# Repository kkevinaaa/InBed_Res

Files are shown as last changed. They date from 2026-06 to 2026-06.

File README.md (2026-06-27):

## 设备设计

### 1.1 目标

本项目制作一个小型立方体番茄钟。设备顶面放置小尺寸单色 OLED 屏幕，用于显示当前时间、倒计时、电量和状态。与顶面相邻的四个侧面均可作为接触桌面的“底面”，用户通过翻滚立方体 90° 启动或切换计时状态。

设备不设置实体按钮，主要依赖姿态变化和摇晃动作交互。外壳面向 3D 打印设计，预留 Type-C 充电口，内部结构便于拆卸、调试和后续缩小体积。

### 1.2 交互与功能

设备默认处于时钟状态，屏幕显示当前时间和电量。长时间无操作后，OLED 熄灭，设备进入低功耗状态。轻微晃动或姿态变化会重新点亮屏幕。

立方体翻滚到指定侧面并稳定放置后，开始一次番茄钟计时，默认 25 分钟。计时过程中，屏幕显示剩余时间。计时结束后，蜂鸣器提醒，并显示结束状态，随后返回时钟状态。

计时过程中检测到暂停姿态，即屏幕面朝上时，设备暂停当前计时，屏幕面重新转向侧面时恢复计时。

计时过程中检测到取消姿态时，设备停止当前计时，短暂显示暂停提示后回到时钟状态。

快速摇晃用于进入 BLE 设置模式。一般情况下 BLE 关闭，只有快速摇晃触发后短时间开启。手机连接后设置当前时间、默认番茄钟时长、蜂鸣提醒方式、屏幕熄灭时间等参数。设置完成或连接超时后关闭 BLE。

```mermaid
stateDiagram-v2
    [*] --> IdleClock

    IdleClock: 时钟显示
    ScreenOff: 熄屏低功耗
    PomodoroRunning: 番茄钟计时
    PomodoroPaused: 暂停提示
    Alarm: 结束提醒
    BLESetting: BLE 设置模式

    IdleClock --> ScreenOff: 无操作超时
    ScreenOff --> IdleClock: 轻微晃动 / 姿态变化

    IdleClock --> PomodoroRunning: 翻滚到计时面并稳定放置
    PomodoroRunning --> Alarm: 倒计时结束
    Alarm --> IdleClock: 蜂鸣提醒结束

    PomodoroRunning --> PomodoroPaused: 翻滚到暂停/取消姿态
    PomodoroPaused --> IdleClock: 暂停提示结束

    IdleClock --> BLESetting: 快速摇晃
    ScreenOff --> BLESetting: 快速摇晃
    BLESetting --> IdleClock: 设置完成 / 连接超时
```

### 1.3 硬件方案

主控使用 ESP32-C3，开发环境为 PlatformIO + Arduino framework。ESP32-C3 负责读取传感器、驱动屏幕、控制蜂鸣器，并通过 BLE 与手机通信。

屏幕使用 SSD1327 单色 OLED。OLED 采用黑底白字显示，没有 TFT 背光常亮问题，适合电池供电设备。第一版只要求清晰显示时间、电量、倒计时和状态提示。

姿态检测使用 SC7A20H 三轴加速度传感器，通过 I2C 与 ESP32-C3 通信。第一阶段使用轮询读取三轴数据，调试六面识别、稳定放置判断、轻微晃动唤醒和快速摇晃检测。后续使用 INT 引脚做低功耗运动中断唤醒。

提醒部分使用 12085 蜂鸣器，阻抗约 16Ω。蜂鸣器通过 MOSFET 或三极管由 GPIO 控制。若使用无源蜂鸣器，ESP32-C3 输出 PWM；若使用有源蜂鸣器，GPIO 只控制开关。

电池使用小型单节聚合物锂电池。充电接口为 Type-C，充电电路使用单节锂电充电保护方案。系统电源可先采用电池升压到 5V 后接 ESP32-C3 开发板，也可后续改为电池经 3.3V 稳压/升降压后直接供电。电量检测第一版使用电阻分压接 ADC，后续可改用 MAX17048 电量计。

### 1.4 低功耗策略

静息状态下关闭 OLED，ESP32-C3 进入低功耗模式，BLE 默认关闭，SC7A20H 保持低功耗运动检测。检测到运动后唤醒主控，再读取完整三轴数据并判断动作类型。

低功耗逻辑的核心是：屏幕不常亮，BLE 不常开，ESP32-C3 不长期高频轮询。第一版先验证功能，后续再优化中断唤醒和静态电流。

### 1.5 第一版范围

第一版验证核心功能，不追求极致小体积和最终外观。目标包括：OLED 显示时间、电量和倒计时；SC7A20H 识别六个方向；翻滚启动 25 分钟计时；翻滚暂停；计时结束蜂鸣提醒；快速摇晃进入 BLE 设置；BLE 设置基础参数；无操作熄屏；晃动唤醒。

第一版外壳先使用较大的 3D 打印结构，优先保证安装、拆卸、测量和调试方便。功能稳定后再优化内部布局、屏幕开窗、接口位置和整体尺寸。

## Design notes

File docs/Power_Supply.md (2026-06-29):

# 供电方案说明

## 1. 当前供电路线

当前供电部分分两条路线推进。第一条路线使用现成 TP4056 充电模块做整机功耗测试，重点测量模块原始静态电流，以及拆除指示灯和限流电阻后的空载、带载电流。该路线用于快速判断现成模块是否适合第一版原型。

第二条路线使用已经完成的 `Cube Power Manager` 电源管理板。该板使用 USB-C 作为 5V 输入，TP4054 负责单节锂电池充电，AP2112K-3.3 负责输出 3.3V，给 MCU、屏幕和传感器供电。相比“电池升压到 5V 再降压到 3.3V”的方案，这一路径更直接，损耗更低，也更接近最终整机结构。

## 2. 方案一：TP4056 模块测试

TP4056 模块作为快速验证方案，优点是便宜、易买、接线简单，适合先测整机平均电流、峰值电流和大致续航。缺点是模块通常带有充电/满电指示灯和额外电阻，会产生持续静态耗电，不一定适合低功耗设备长期使用。

模块到货后先测原始状态下的静态电流，再拆除 LED 和相关限流电阻后重新测量。若拆除指示灯后静态电流足够低，可以作为早期原型供电方案；若静态电流仍然偏大，则只作为测试工具，不进入最终设计。

## 3. 方案二：Cube Power Manager

`Cube Power Manager` 是当前自制供电板方案。它集成 USB-C 输入、单节锂电池充电、电池供电路径、3.3V 稳压输出、电池电压检测和测试点，目标是验证最终设备所需的基础电源链路。

USB-C 只用于取 5V 电源，不做数据通信。CC1 和 CC2 使用下拉电阻声明设备端，从而让普通 USB-C 电源正常输出 5V。USB 输入进入 VIN 后，一路供给充电芯片，另一路通过电源路径给系统供电。

TP4054 负责单节锂电池充电。PROG 电阻设定充电电流，CHRG 引脚可用于充电状态指示。电池端引出 VBAT，同时保留电池接口和测试点，方便测量充电状态、电池电压和充电电流。

系统电源路径使用 VIN、VBAT 和 VCC 三个核心节点。USB 插入时，系统优先由 VIN 供电；USB 拔出时，系统由电池供电。当前设计中使用肖特基二极管和 PMOS 构成基础电源切换路径，并预留通过二极管方式验证电源 OR 的可能性。

AP2112K-3.3 将系统电源稳压为 3.3V。3.3V 输出用于 MCU、OLED 和 SC7A20H 等低压器件。该方案避免先升压再降压，结构简单，但需要注意单节锂电电压接近 3.3V 时，LDO 会逐渐失去稳压余量。

BAT_ADC 用于检测电池电压。电池电压经过电阻分压后送入 MCU ADC，避免超过 MCU 引脚耐压。采样点并联小电容用于降低噪声和稳定 ADC 读数。

## 4. 测试点与后续验证

电源板应重点测试 VIN、VBAT、VCC、3V3、GND、BAT_ADC 和充电状态信号。测试顺序从 USB 输入开始，再检查充电芯片、电池端、电源路径、LDO 输出和 ADC 检测。

第一次上电时先不接 MCU 负载，单独确认 3.3V 输出正常。随后接入 MCU 和屏幕，观察启动瞬间是否掉压、LDO 是否发热、电池供电是否稳定、USB 插拔时系统是否异常复位。

后续若要优化低功耗，优先检查三处：充电模块或指示灯带来的静态耗电，LDO 自身静态电流，以及电池电压检测分压电阻的持续耗电。

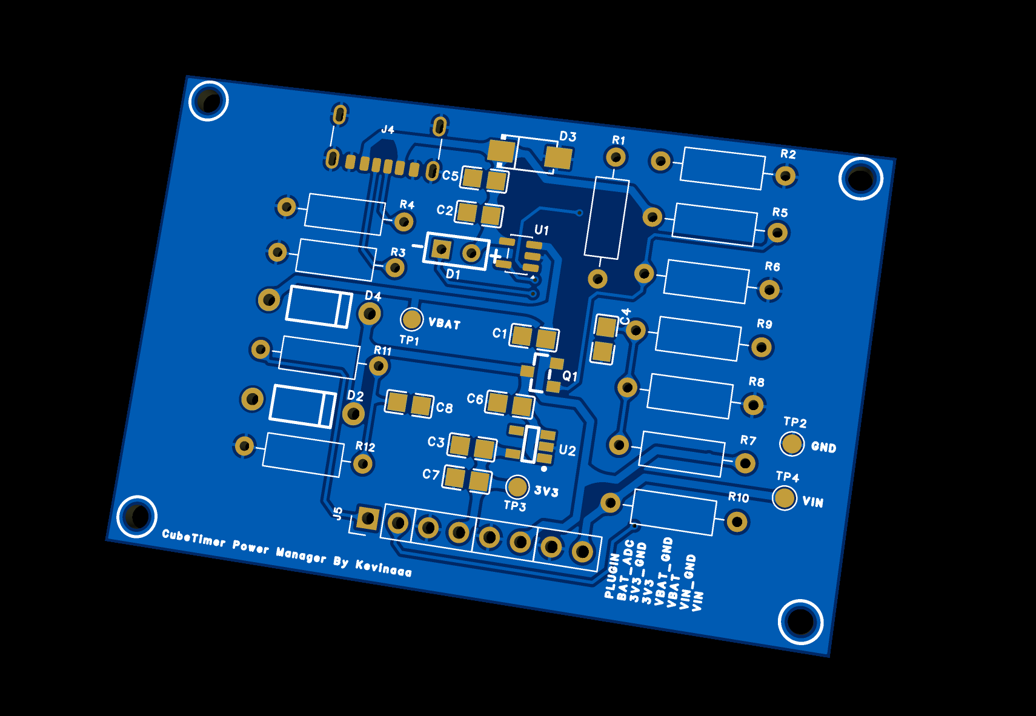
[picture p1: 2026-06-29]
hardware/power_manager/Pics/d412c011-9bdf-4567-bb50-f9bbbd0711b7.png

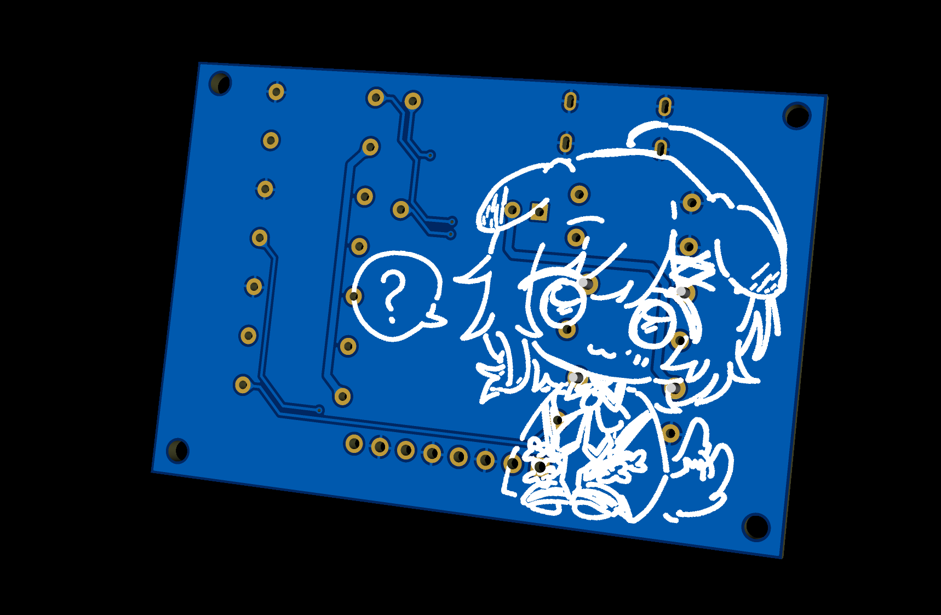
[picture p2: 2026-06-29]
hardware/power_manager/Pics/3ba6615dcab4c9ef26ad207464008806.png

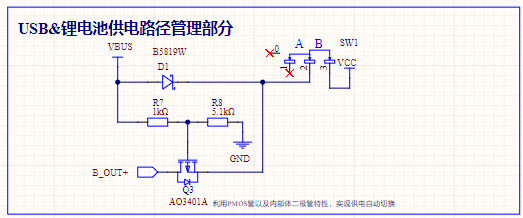
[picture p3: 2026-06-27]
docs/reference/旁路供电.png

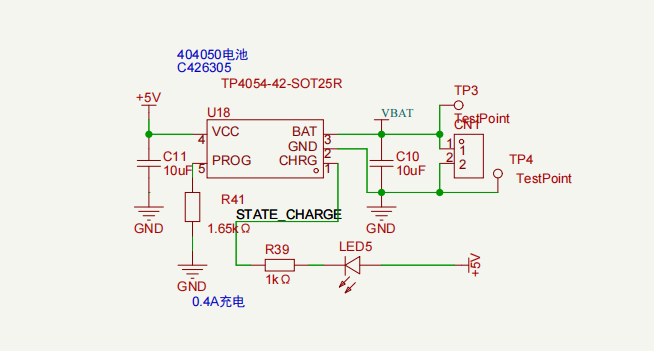
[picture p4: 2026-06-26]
docs/reference/TP4054.png

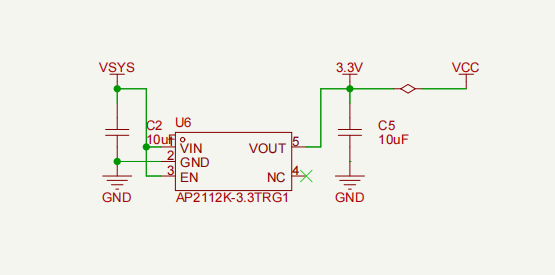
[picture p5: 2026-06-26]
docs/reference/AP2112K.png

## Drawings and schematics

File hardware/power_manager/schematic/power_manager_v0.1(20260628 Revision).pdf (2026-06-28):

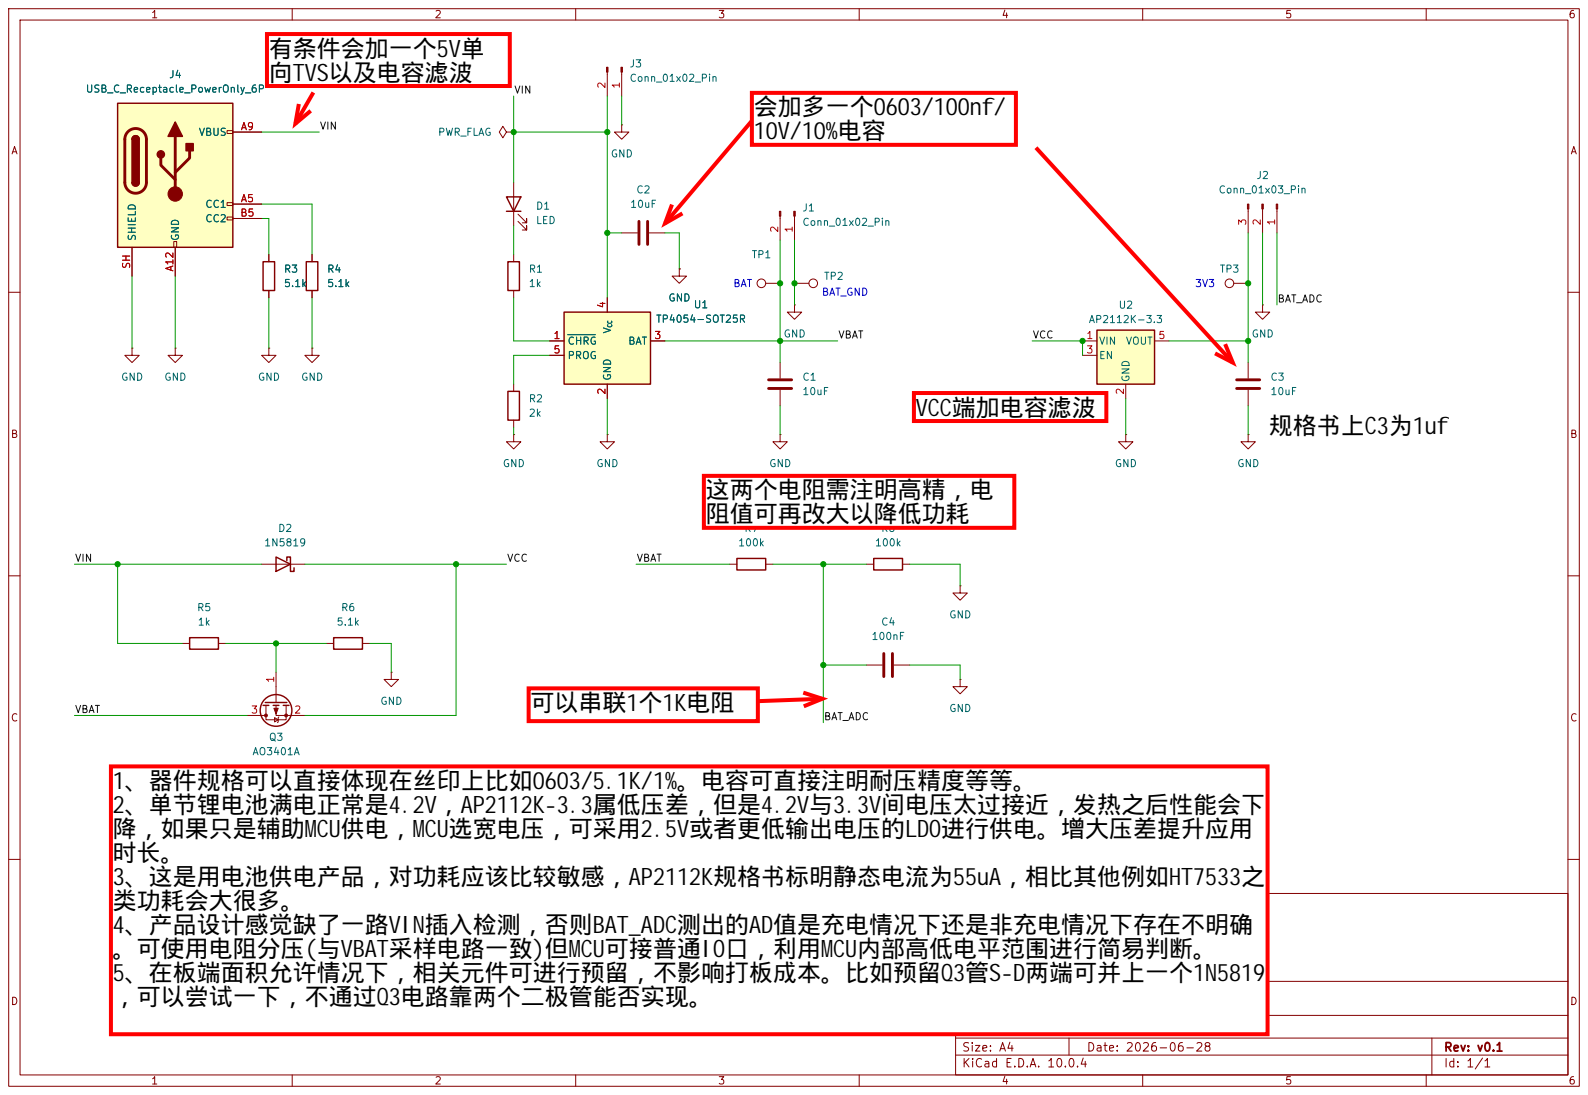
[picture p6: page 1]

Sheet: /
File: power_manager.kicad_sch
Title: Cube Power Manager

Size: A4 | Rev: v0.1
KiCad E.D.A. 10.0.4 | Id: 1/1

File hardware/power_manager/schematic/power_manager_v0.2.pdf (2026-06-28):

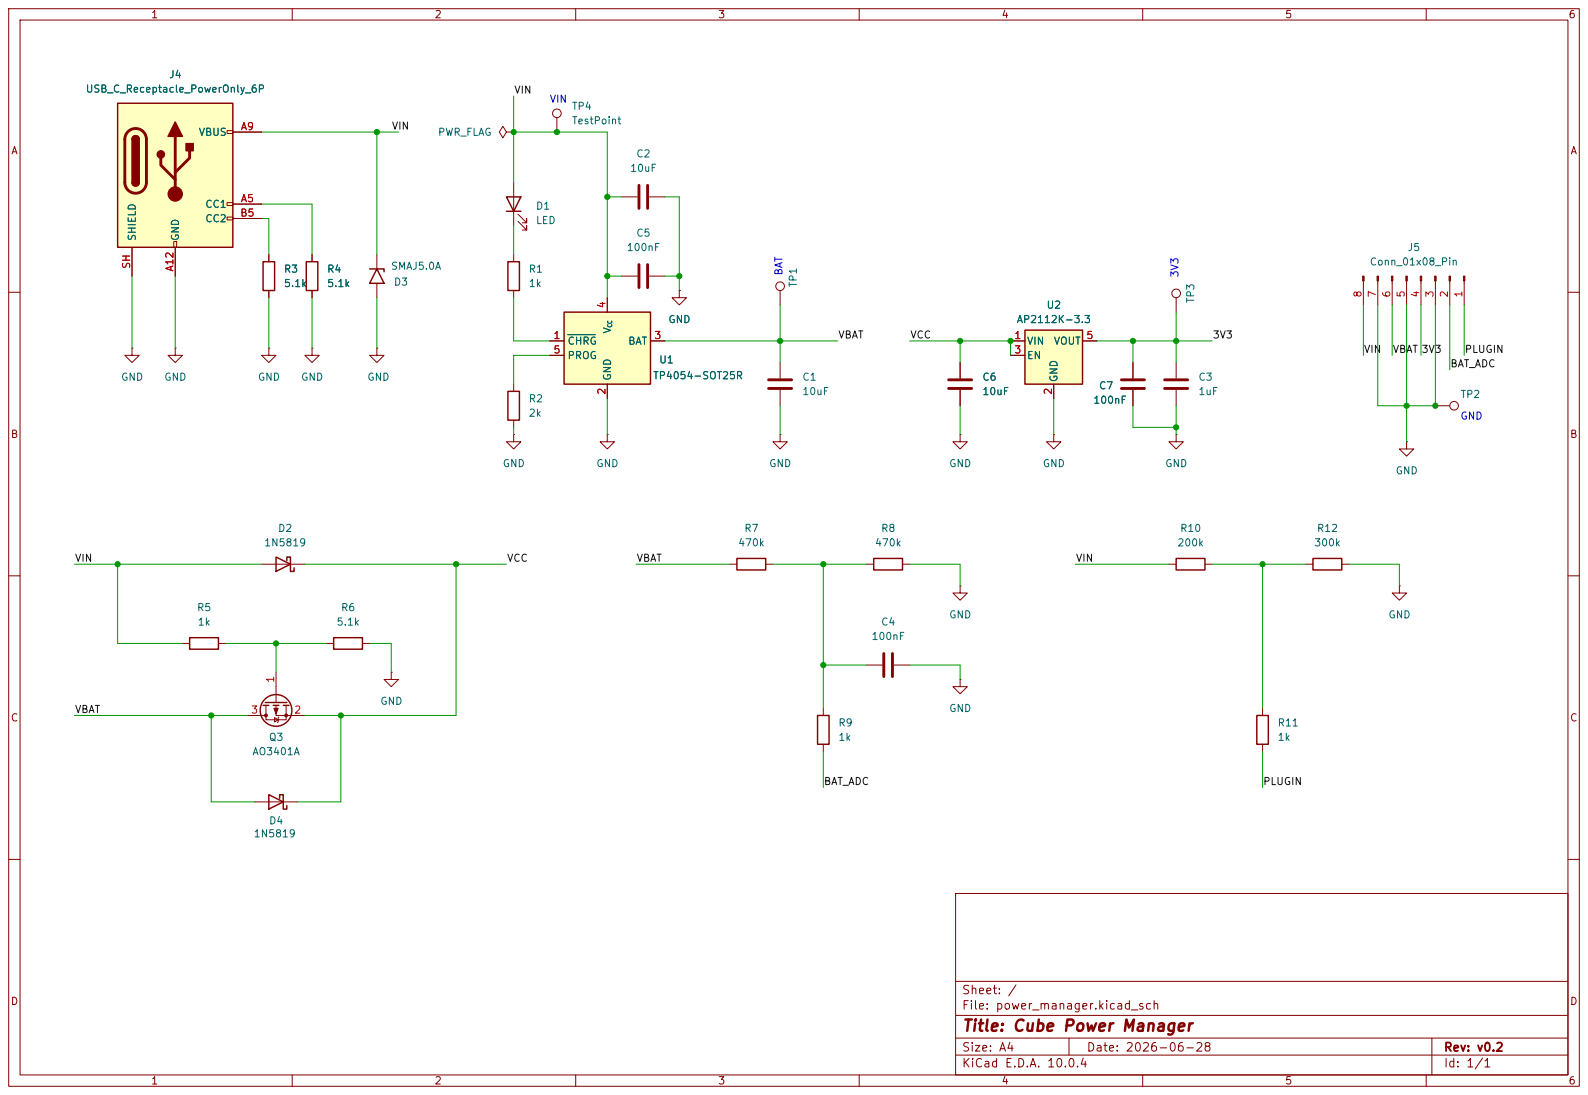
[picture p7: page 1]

Sheet: /
File: power_manager.kicad_sch
Title: Cube Power Manager

Size: A4 | Rev: v0.2
KiCad E.D.A. 10.0.4 | Id: 1/1

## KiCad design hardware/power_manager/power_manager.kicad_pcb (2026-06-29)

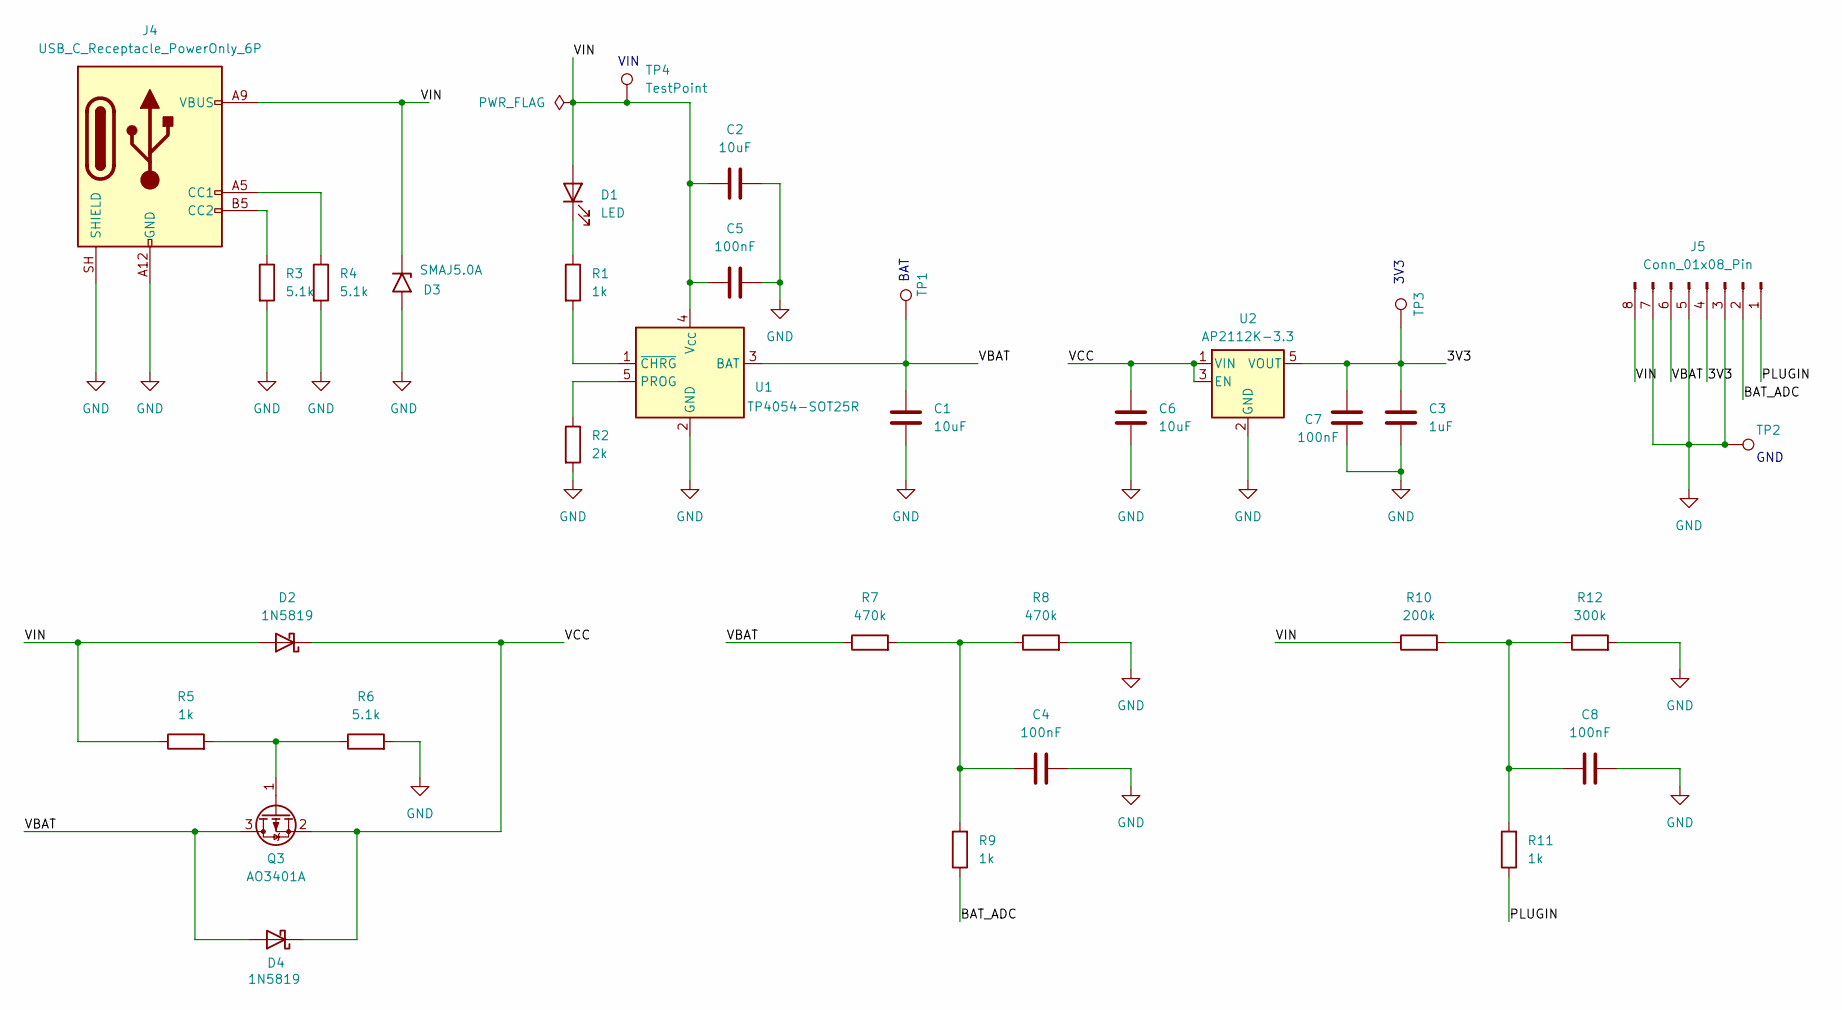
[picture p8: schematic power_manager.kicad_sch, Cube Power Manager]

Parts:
C1, C2, C6: 10uF; C_0805_2012Metric
C3: 1uF; C_0805_2012Metric
C4, C5, C7, C8: 100nF; C_0805_2012Metric
D1: LED; LED_D3.0mm
D2, D4: 1N5819; D_DO-41_SOD81_P10.16mm_Horizontal
D3: SMAJ5.0A; D_SMA
J4: USB_C_Receptacle_PowerOnly_6P; USB_C_Receptacle_GCT_USB4125-xx-x_6P_TopMnt_Horizontal
J5: Conn_01x08_Pin; PinHeader_1x08_P2.54mm_Vertical
Q3: AO3401A; SOT-23
R1, R5, R9, R11: 1k; R_Axial_DIN0207_L6.3mm_D2.5mm_P10.16mm_Horizontal
R2: 2k; R_Axial_DIN0207_L6.3mm_D2.5mm_P10.16mm_Horizontal
R3, R4, R6: 5.1k; R_Axial_DIN0207_L6.3mm_D2.5mm_P10.16mm_Horizontal
R7, R8: 470k; R_Axial_DIN0207_L6.3mm_D2.5mm_P10.16mm_Horizontal
R10: 200k; R_Axial_DIN0207_L6.3mm_D2.5mm_P10.16mm_Horizontal
R12: 300k; R_Axial_DIN0207_L6.3mm_D2.5mm_P10.16mm_Horizontal
TP1, TP2, TP3: TestPoint_Pad_D1.5mm
TP4: TestPoint; TestPoint_Pad_D1.5mm
U1: TP4054-SOT25R; TSOT-23-5
U2: AP2112K-3.3; SOT-23-5

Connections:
/3V3: C3.1, C7.2, J5.4, TP3.1 (1_1), U2.5 (VOUT)
/BAT_ADC: J5.2, R9.1
/PLUGIN: J5.1, R11.1
/VBAT: C1.1, D4.2 (A), J5.6, Q3.3 (D), R7.1, TP1.1 (1_1), U1.3 (BAT)
/VCC: C6.1, D2.1 (K), D4.1 (K), Q3.2 (S), U2.1 (VIN), U2.3 (EN)
/VIN: C2.1, C5.1, D1.2 (A), D2.2 (A), D3.1 (A1), J4.A9 (VBUS), J4.B9 (VBUS), J5.8, R5.1, R10.1, TP4.1 (1_1), U1.4 (V_{CC})
GND: C1.2, C2.2, C3.2, C4.2, C5.2, C6.2, C7.1, C8.2, D3.2 (A2), J4.A12 (GND), J4.B12 (GND), J4.SH (SHIELD), J5.3, J5.5, J5.7, R2.2, R3.2, R4.2, R6.2, R8.2, R12.2, TP2.1 (1_1), U1.2 (GND), U2.2 (GND)
unnamed: C4.1, R7.2, R8.1, R9.2
unnamed: C8.1, R10.2, R11.2, R12.1
unnamed: D1.1 (K), R1.1
unnamed: J4.A5 (CC1), R4.1
unnamed: J4.B5 (CC2), R3.1
unnamed: Q3.1 (G), R5.2, R6.1
unnamed: R2.1, U1.5 (PROG)
unnamed: R1.2, U1.1 (~CHRG)

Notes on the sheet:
3V3
BAT
VIN
GND

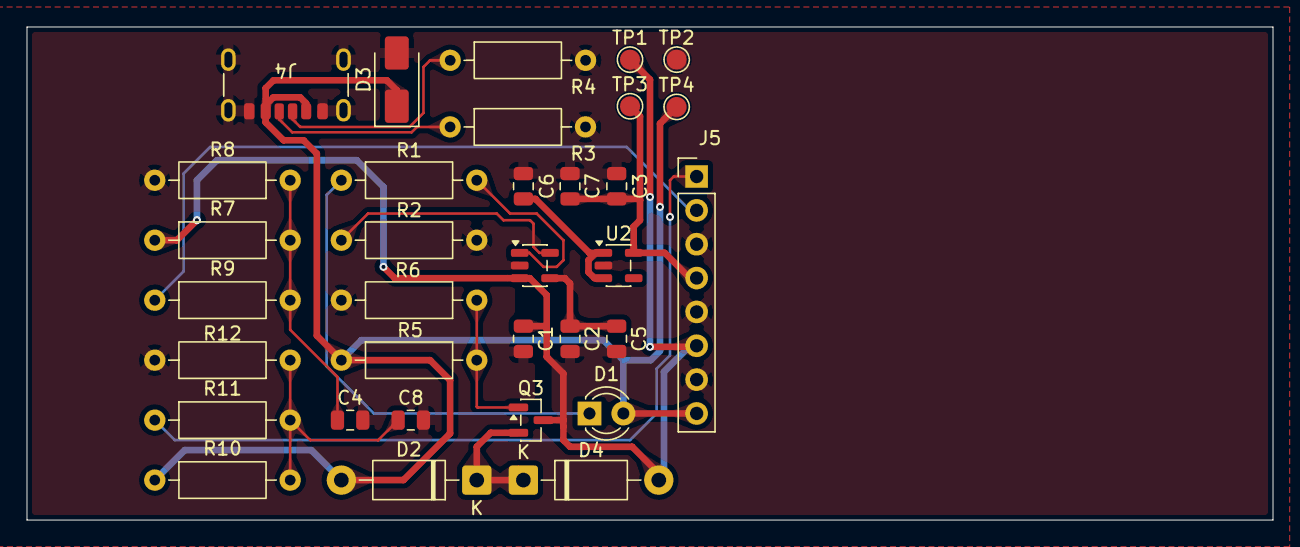
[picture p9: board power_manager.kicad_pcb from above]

Board: 2 copper layers, 93.5 x 37.0 mm, 33 parts (0 on the bottom side), 15 nets.

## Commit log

2026-06-26 Add:Layout, Readme, references
    [power_manager.kicad_pcb, power_manager.kicad_sch]
2026-06-27 Fix: Readme
    [power_manager.kicad_sch]
2026-06-27 Imp: Powermanager
    [power_manager.kicad_sch]
2026-06-28 Imp: powermanager schematic v0.2
    [power_manager.kicad_pcb, power_manager.kicad_sch]
2026-06-29 Add: PCB
    [power_manager.kicad_pcb, power_manager.kicad_sch]
2026-06-29 Imp: PCB FInish
2026-06-29 Add: Power_Supply.md
